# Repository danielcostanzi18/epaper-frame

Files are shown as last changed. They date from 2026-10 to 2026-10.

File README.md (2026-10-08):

# E-paper frame

3D-printed enclosure for a Waveshare 7.5" e-paper panel (800x480) driven by the Waveshare
e-Paper ESP32 Driver Board. It hangs on a wall (keyholes) or stands on a desk (removable
wedge feet), and has a Gateron low-profile key switch on the back.

- `docs/REQUIREMENTS.md` – hardware specs and design decisions
- `docs/ASSEMBLY.md` – print settings and assembly steps
- `docs/BOM.md` / `docs/bom.csv` – bill of materials
- `cad/epaper_frame.py` – parametric FreeCAD model (all parts); STL/STEP files and the coloured
  assembly are in `cad/out/`, earlier iterations in `cad/archive/`

Rebuild (FreeCAD 0.19):

```
cd cad
freecadcmd epaper_frame.py
QT_QPA_PLATFORM=offscreen freecad colour_assembly.py
```

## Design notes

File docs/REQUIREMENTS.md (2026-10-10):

# E-Paper Photo Frame — Requirements

3D-printed enclosure for a 7.5" e-paper panel driven by an ESP32. It can hang
on a wall or stand on a desk using removable feet.

## Hardware

| Item | Size (mm) | Notes |
|---|---|---|
| Waveshare 7.5" e-Paper raw panel V2 (800x480) | 170.2 x 111.2 x 1.18 | Active area 163.2 x 97.92. Borders: 3.5 on the sides and top, 9.78 on the FPC edge (the driver chip sits there) |
| Panel FPC tail | ~22 wide, 24 long | On a long edge, centred ~78 mm from one short end |
| FPC adapter board | 31.75 x 17.50 | Plugs onto the panel's FPC tail; FFC extension cable goes to the ESP32 |
| Waveshare e-Paper ESP32 Driver Board | 29.46 x 48.25 | **No mounting holes.** USB on a short edge, ESP32 module at the other end, FPC connector on a long side |
| Gateron KS-33 Low Profile 2.0 key switch (no keycap) | 15 x 15 top housing, 14 x 14 plate cutout, 12.2 total height, 3.0 travel | Clips into a 1.2 mm plate; 2 pins at (-4.4, 4.7) and (2.6, 5.75) from centre. Height split above/below the plate is assumed (6.0 / 6.2 incl. pins) |

Source: Waveshare panel spec PDF (7.5inch_e-Paper_V2_Specification.pdf, p.5) and the
ESP32 driver board manual. Board sizes were measured or confirmed by the user.

## Functional requirements
1. The panel is held in a rabbet (incastro). The bezel overlaps only the inactive border.
2. The panel must be removable without tools other than a screwdriver, and nothing may be glued to it.
3. The ESP32 sits behind the panel. It must not touch the panel or be stuck to it.
4. The ESP32 is held without mounting holes (clamped, not screwed).
5. USB power must be reachable from outside.
6. Wall mounting: keyhole slots.
7. Desk use: removable wedge feet screwed to the back, with nothing sticking out in front of the frame.

## Manufacturing constraints
- FDM, PLA, 220 x 220 mm bed. Every part prints flat without supports.
- Panel pocket (iteration 5): 1.5 mm bigger than the panel + clearance on every side, so the
  panel's sharp corners and edges touch nothing (a printer always rounds inside corners a little).
  The panel is located by 8 teeth, two per side at 1/4 and 3/4 of each edge, 8 mm wide, with
  0.45 mm clearance to the panel (0.3 mm printed too tight) and a 0.6 mm lead-in chamfer at the back.
- Fasteners: M3 button-head screws driven straight into the plastic, into Ø2.7 mm pilot holes
  (the first tightening cuts the thread). Every screw gets at least 4 mm of thread in plastic.
  Each hole has a 0.5 mm 45° chamfer at its mouth (Ø3.7 at the surface) to guide the screw in.

## Design decisions (implemented in cad/epaper_frame.py)
- Orientation: landscape, with the FPC edge at the bottom (the wide 9.78 mm border hides there).
- Bezel window: active area + 0.5 mm per side, offset to match the asymmetric border.
  The visible bezel is 17.4 mm on the sides and top and 23.7 mm at the bottom: wider at the bottom
  because the pixels sit off-centre on the glass (kept on purpose).
- The panel is pressed from behind by two vertical **panel straps** (14 x 132 x 4 mm, iteration 5),
  with 0.5 mm foam tape between straps and panel. Each strap is screwed to the bezel at both ends
  (4x M3 in total). They replace the full backer plate of iteration 4, which used ~5x more plastic.
- The bezel's back face has a 0.5 mm relief over the driver-chip strip, so nothing presses on the chip.
- A 50 mm wide relief at the bottom edge leaves room for the FPC tail to fold behind the panel.
- The adapter board lies on the back of the panel between the two straps, held by its two cables.
  There is 6 mm of free space either side of it, because the tail position depends on which end
  the 78 mm is measured from.
- The ESP32 sits on the back cover on 4 support pads. Corner locators hold it in place sideways,
  and a screwed strap with a foam pad presses on the module can.
- The ESP32 lies with its long edge horizontal and its USB end against the right-hand short wall
  (seen from the back). A 14 x 9 mm slot in that wall, centred on the board, lets the plug go in from outside.
- 2 keyholes, 100 mm apart, on the back cover (screw head up to 8 mm, shank up to 4 mm).
- 2 removable wedge feet (20 x 34 x 45 mm), each held by 2 screws straight into the back cover.
  The frame stands on its rear bottom edge plus the wedges, leaning back 20°. With no front
  support, 15° would leave the centre of mass only ~5 mm behind the tipping edge; 20° gives
  ~12 mm. The script checks this margin on every build.
- Overall size: 199.1 x 140.1 x 23.5 mm.
- Softened edges (iteration 3): the four vertical corners are rounded R4 on both the frame and
  the cover, so the side profile runs continuously across the joint. Edges that print on the bed
  get 45° chamfers: bezel front 1.5 mm, a 1 mm bevel round the viewing window, back cover 1 mm.
  The joint between frame and cover is left sharp so the two parts meet flush.
- Key switch (iteration 4): on the back cover, top centre, in line with the keyholes. It clips from
  outside into a 14 x 14 cutout in a 1.2 mm floor at the bottom of an 18 x 18 mm well, 6.5 mm deep,
  with a 1 mm chamfer round the rim. The bare stem stays 0.5 mm below the back surface, so the
  frame still sits flat on a wall. The cup sits 0.8 mm clear of the panel-strap level, allowing for the pins
  and soldered wires.
- Previous iterations are kept untouched in cad/archive/: iteration2/ (sharp edges), iteration3/
  (softened edges, no key switch), iteration4_heatset/ (heat-set inserts) and iteration4/ (full
  backer plate with adapter recess).

## Open items to verify on the real parts
1. The FPC tail is on the long edge with the wider (9.78 mm) border. If the window ends up
   off-centre, swap `AA_BORDER_TOP` and `AA_BORDER_FPC` in the script.
2. The ESP32 USB connector is assumed to be centred on its short edge, about 1.6 mm above the PCB.
3. The module can is assumed to be centred 15.5 mm from the board end opposite the USB.
   The strap must land on the metal can, not on the antenna.
4. Pilot hole size (`PILOT_D` = 2.7 mm): print a test piece. Go 2.5 if the screws feel loose,
   2.8 if the plastic cracks. Holes in the feet wear fastest, since they are removed most.
5. Key switch heights: measure the height above the plate (housing top to stem tip) and below it
   (to the pin tips); `KS_ABOVE` and `KS_BELOW` in the script assume 6.0 and 6.2 mm.

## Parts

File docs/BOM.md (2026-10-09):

# Bill of Materials — e-paper frame (iteration 4)

Same data as a spreadsheet: `bom.csv`. Part sizes and filament come from `cad/out/` (iteration 4).

## 1. Electronics

| # | Item | Spec | Qty | Used for | Notes |
|---|---|---|---|---|---|
| E1 | Waveshare 7.5" e-Paper raw panel V2 | 800x480, black/white, 170.2 x 111.2 x 1.18 mm | 1 | Display | |
| E2 | Waveshare e-Paper ESP32 Driver Board | 29.46 x 48.25 mm, USB-C | 1 | Controller | Ships with E3 and E4 |
| E3 | e-Paper FPC adapter board | 31.75 x 17.50 mm | 1 | Panel FPC → FFC | Included with E2 |
| E4 | FFC extension cable | 24-pin, 0.5 mm pitch | 1 | Adapter → ESP32 | Included with E2 |
| E5 | Gateron KS-33 Low Profile 2.0 switch | 3-pin, plate-mount for a 1.2 mm plate, any colour | 1 | Button on the back | Used without a keycap |
| E6 | Hook-up wire | AWG 26–28, ~2 x 25 cm | 1 set | Switch → ESP32 GPIO + GND | Solder to the switch pins |
| E7 | USB-C cable + 5 V supply | ≥ 0.5 A | 1 | Power | The plug body must pass a 14 x 9 mm slot |

## 2. Printed parts (PLA, no supports)

| # | Part | File | Qty | Size (mm) | Filament (est.) | Print orientation |
|---|---|---|---|---|---|---|
| P1 | Frame (bezel + walls) | frame.stl | 1 | 199.1 x 140.1 x 20.5 | ~80 g | Front face down |
| P2 | Backer | backer.stl | 1 | 170.7 x 132.1 x 4.0 | ~70 g | Flat back face down |
| P3 | Back cover | back_cover.stl | 1 | 199.1 x 140.1 x 9.7 | ~95 g | Outer face down |
| P4 | ESP32 strap | esp32_strap.stl | 1 | 10.0 x 47.5 x 2.5 | ~1.5 g | Flat |
| P5 | Desk wedge foot | foot.stl | 2 | 20.0 x 34.0 x 45.0 | ~10 g each | Screw face down |
| | **Total** | | | | **~265 g** | Solid parts would be ~335 g |

Filament estimates assume 3 walls, 4 top/bottom layers and 20 % infill. Every part fits a 220 x 220 mm bed.

## 3. Fasteners

| # | Item | Spec | Qty | Used for |
|---|---|---|---|---|
| F1 | Button-head screw | M3 x 10 | 8 | 4 back cover → frame corners, 4 feet (2 per foot) |
| F2 | Button-head screw | M3 x 6 | 4 | Backer → frame |
| F3 | Button-head screw | M3 x 8 | 2 | ESP32 strap → back cover |
| F4 | Wall screw + plug | Head Ø ≤ 8 mm, shank Ø ≤ 4 mm | 2 | Wall mounting, 100 mm apart. Optional, wall use only |

All screws thread straight into Ø2.7 mm pilot holes in the plastic; the first tightening cuts the
thread. Plain M3 machine screws work. Don't overtighten, and buy a couple of spares.

## 4. Consumables

| # | Item | Spec | Qty | Used for |
|---|---|---|---|---|
| C1 | Foam tape | 0.5 mm thick, ~5 mm wide, ~60 cm | 1 | Between backer and panel, round the edge |
| C2 | Foam pad | 1 mm thick, ~10 x 15 mm | 1 | Between strap and ESP32 module can |
| C3 | Thin double-sided or Kapton tape | small piece | 1 | Optional: holds the adapter board in its recess (never on the panel) |

## 5. Tools
Soldering iron (switch wires), M3 hex/screwdriver, flush cutters.

## Not included / open
- No battery: the ESP32 board has a LiPo connector, but the enclosure has no battery bay yet.
- The key switch heights are assumed (6.0 mm above / 6.2 mm below the plate). Check them on the
  real switch before printing P3.

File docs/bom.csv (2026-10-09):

ID | Category | Item | Spec | Qty | Unit | Used for | Notes
E1 | Electronics | Waveshare 7.5in e-Paper raw panel V2 | 800x480 B/W, 170.2 x 111.2 x 1.18 mm | 1 | pcs | Display
E2 | Electronics | Waveshare e-Paper ESP32 Driver Board | 29.46 x 48.25 mm, USB-C | 1 | pcs | Controller | Ships with E3 and E4
E3 | Electronics | e-Paper FPC adapter board | 31.75 x 17.50 mm | 1 | pcs | Panel FPC to FFC | Included with E2
E4 | Electronics | FFC extension cable | 24-pin, 0.5 mm pitch | 1 | pcs | Adapter to ESP32 | Included with E2
E5 | Electronics | Gateron KS-33 Low Profile 2.0 switch | 3-pin, plate mount, 1.2 mm plate | 1 | pcs | Button on the back | No keycap
E6 | Electronics | Hook-up wire | AWG 26-28, 2 x 25 cm | 1 | set | Switch to ESP32 GPIO + GND
E7 | Electronics | USB-C cable + 5 V supply | >= 0.5 A | 1 | pcs | Power | Plug body must pass a 14 x 9 mm slot
P1 | Printed | Frame | frame.stl 199.1 x 140.1 x 20.5 mm | 1 | pcs | Bezel + walls | PLA ~80 g, front face down
P2 | Printed | Backer | backer.stl 170.7 x 132.1 x 4.0 mm | 1 | pcs | Presses panel into bezel | PLA ~70 g, flat back face down
P3 | Printed | Back cover | back_cover.stl 199.1 x 140.1 x 9.7 mm | 1 | pcs | Closes the enclosure | PLA ~95 g, outer face down
P4 | Printed | ESP32 strap | esp32_strap.stl 10.0 x 47.5 x 2.5 mm | 1 | pcs | Clamps ESP32 | PLA ~1.5 g, flat
P5 | Printed | Desk wedge foot | foot.stl 20.0 x 34.0 x 45.0 mm | 2 | pcs | Desk stand (20 deg) | PLA ~10 g each, screw face down
F1 | Fastener | Button-head screw | M3 x 10 | 8 | pcs | 4 cover to frame corners, 4 feet | Into 2.7 mm pilot holes in plastic
F2 | Fastener | Button-head screw | M3 x 6 | 4 | pcs | Backer to frame | Into 2.7 mm pilot holes in plastic
F3 | Fastener | Button-head screw | M3 x 8 | 2 | pcs | ESP32 strap to cover | Into 2.7 mm pilot holes in plastic
F4 | Fastener | Wall screw + plug | head <= 8 mm, shank <= 4 mm | 2 | pcs | Wall mounting (optional) | 100 mm apart
C1 | Consumable | Foam tape | 0.5 mm thick, 5 mm wide | 60 | cm | Backer to panel edge
C2 | Consumable | Foam pad | 1 mm thick, 10 x 15 mm | 1 | pcs | Strap to ESP32 module can
C3 | Consumable | Double-sided or Kapton tape | small piece | 1 | pcs | Adapter board in its recess (optional) | Never on the panel

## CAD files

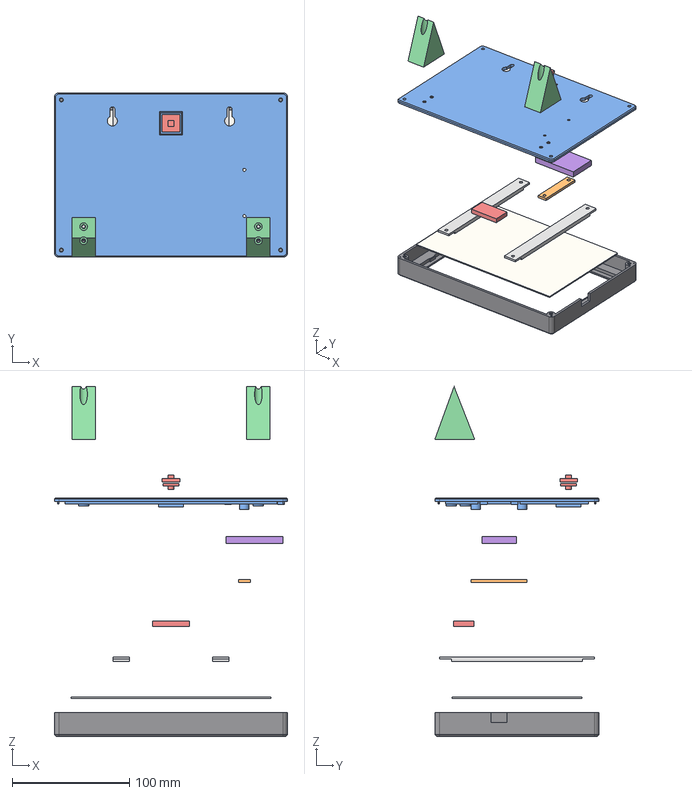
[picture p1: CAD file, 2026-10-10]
cad/out/assembly_exploded.FCStd
199.1 x 140.1 x 298.5 mm
frame
ref_panel
panel_strap_1
panel_strap_2
ref_adapter
esp32_strap
ref_esp32
ref_key_switch
back_cover
foot_1
foot_2

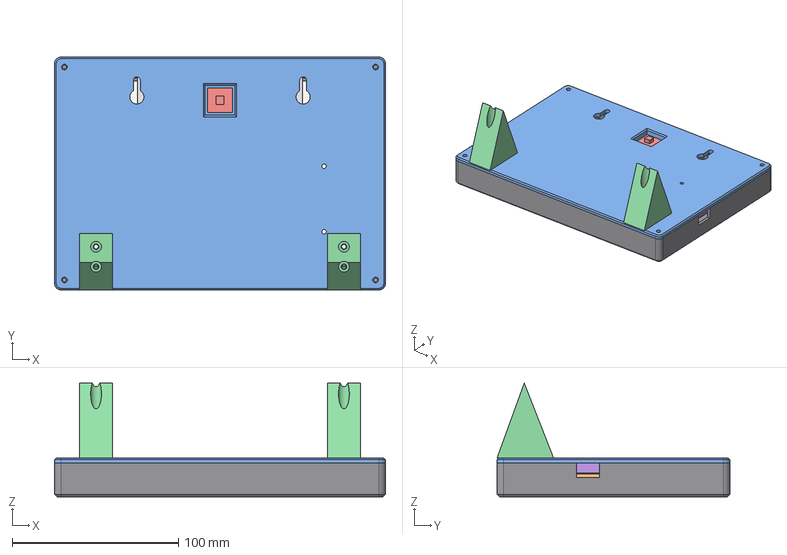
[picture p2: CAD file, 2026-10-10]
cad/out/assembly.FCStd
199.1 x 140.1 x 68.5 mm
frame
ref_panel
panel_strap_1
panel_strap_2
ref_adapter
esp32_strap
ref_esp32
ref_key_switch
back_cover
foot_1
foot_2

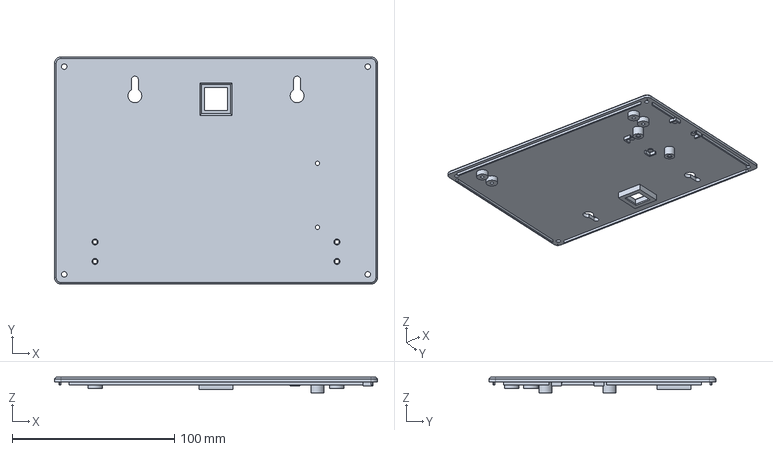
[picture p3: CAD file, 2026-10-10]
cad/out/back_cover.step
199.1 x 140.1 x 9.70 mm

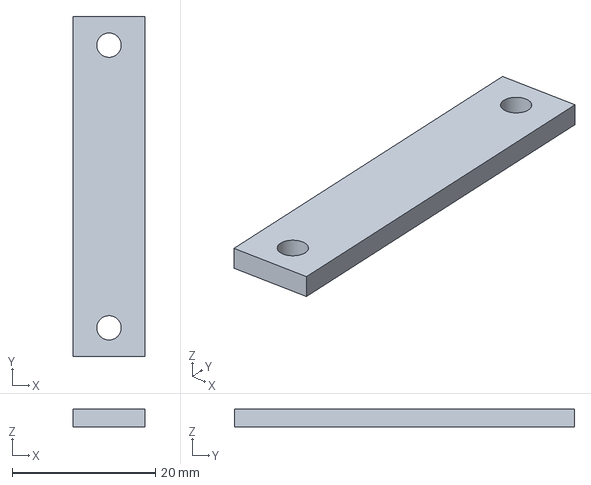
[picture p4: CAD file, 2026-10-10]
cad/out/esp32_strap.step
10.0 x 47.5 x 2.50 mm

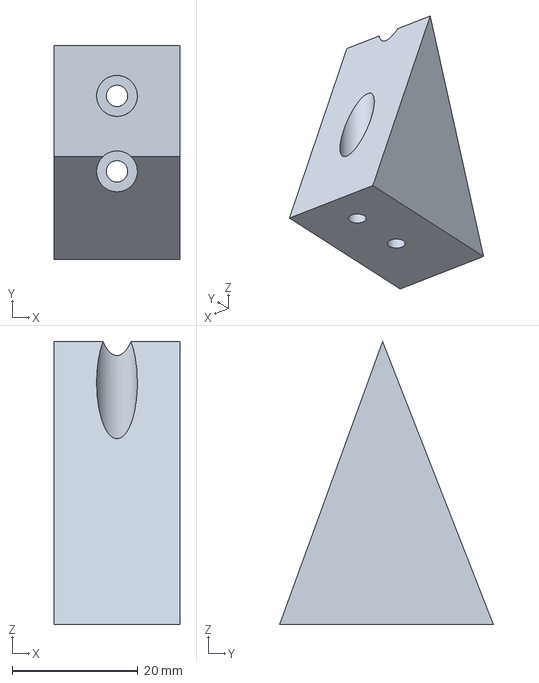
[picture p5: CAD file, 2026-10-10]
cad/out/foot.step
20.0 x 34.0 x 45.0 mm

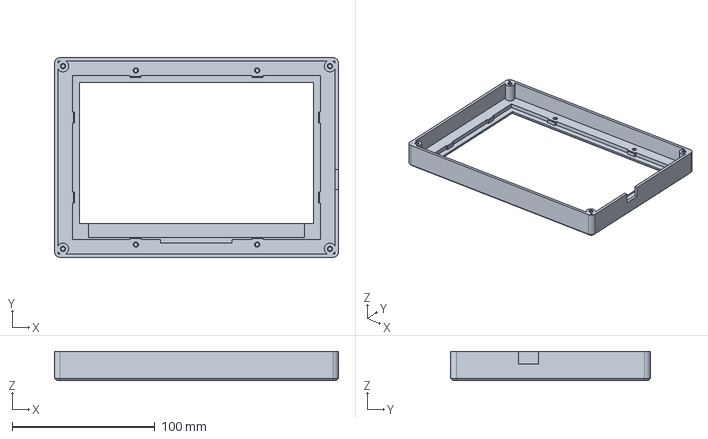
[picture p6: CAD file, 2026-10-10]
cad/out/frame.step
199.1 x 140.1 x 20.5 mm

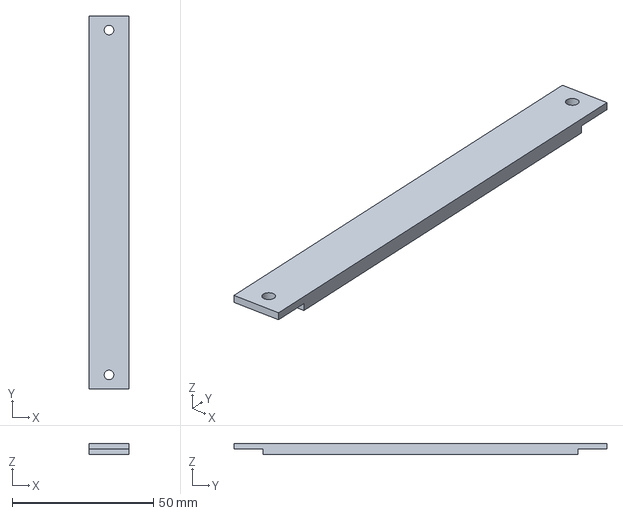
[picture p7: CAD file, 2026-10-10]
cad/out/panel_strap.step
14.0 x 132.1 x 4.00 mm

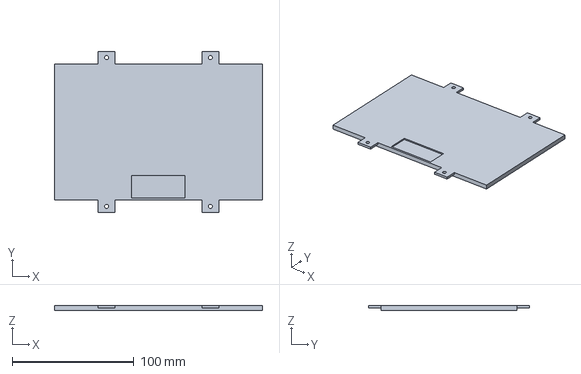
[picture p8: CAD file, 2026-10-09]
cad/out/backer.step
170.7 x 132.1 x 4.00 mm

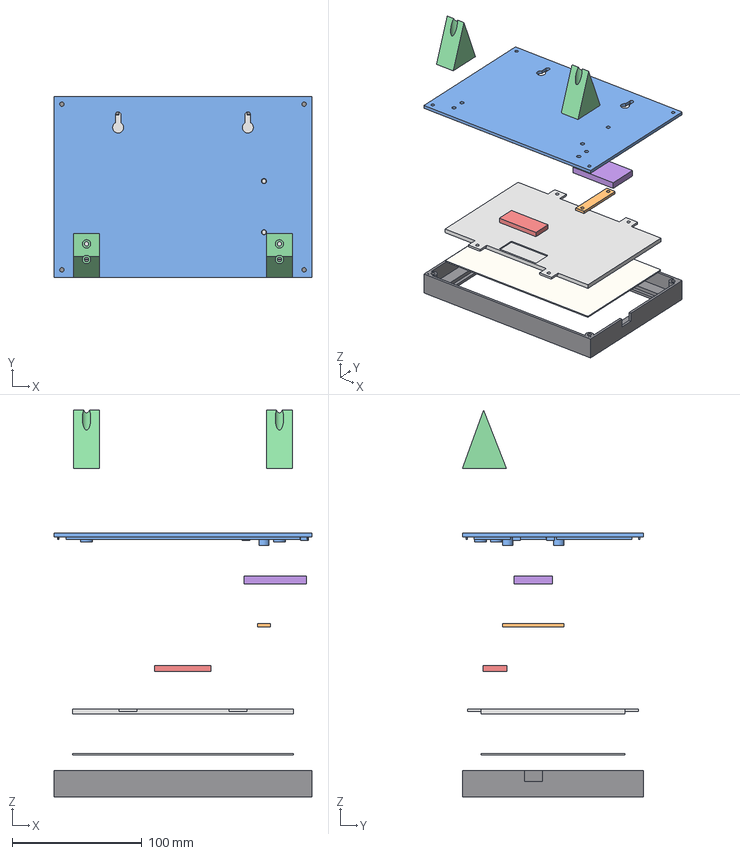
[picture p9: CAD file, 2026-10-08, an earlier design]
cad/archive/iteration2/assembly_exploded.FCStd
198.8 x 139.8 x 298.5 mm
frame
ref_panel
backer
ref_adapter
esp32_strap
ref_esp32
back_cover
foot_1
foot_2

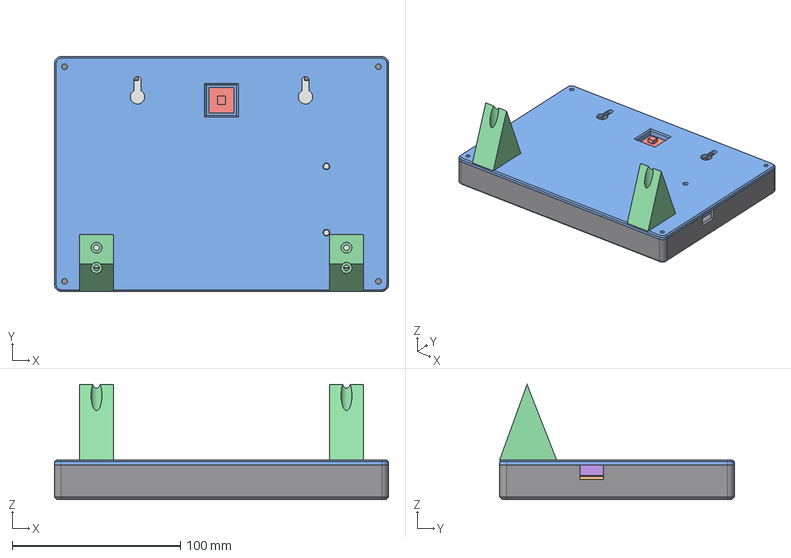
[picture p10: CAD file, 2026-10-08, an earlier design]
cad/archive/iteration4_heatset/assembly.FCStd
198.8 x 139.8 x 68.5 mm
frame
ref_panel
backer
ref_adapter
esp32_strap
ref_esp32
ref_key_switch
back_cover
foot_1
foot_2

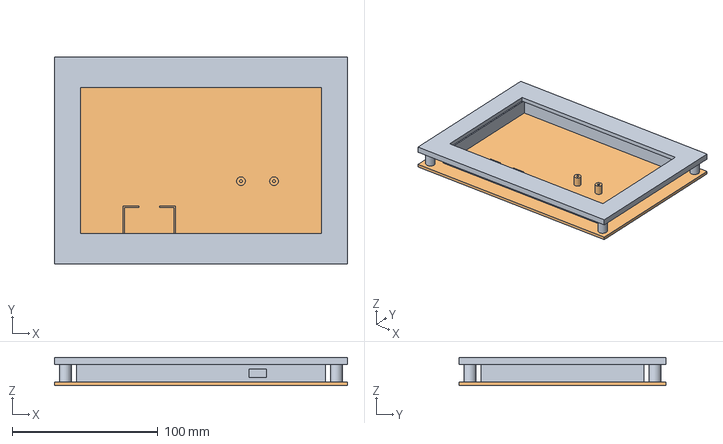
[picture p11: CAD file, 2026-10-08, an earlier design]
cad/archive/iteration2_assembly.FCStd
200.8 x 141.8 x 19.5 mm
Frame
BackCover

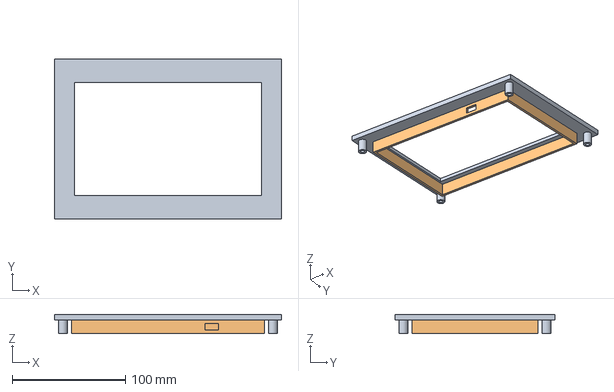
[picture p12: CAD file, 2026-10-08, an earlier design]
cad/archive/iteration2_frame.step
200.8 x 141.8 x 17.0 mm

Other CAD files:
cad/archive/iteration3/assembly_exploded.FCStd
cad/archive/iteration4/assembly.FCStd
cad/archive/iteration3/assembly.FCStd
cad/archive/iteration4/assembly_exploded.FCStd
cad/archive/iteration4_heatset/assembly_exploded.FCStd
cad/archive/iteration2/assembly.FCStd
cad/archive/iteration1_frame.FCStd
cad/archive/iteration1_frame.step
cad/archive/iteration1_frame.stl
cad/archive/iteration2/assembly.obj
cad/archive/iteration2/assembly_exploded.obj
cad/archive/iteration2/back_cover.step
cad/archive/iteration2/back_cover.stl
cad/archive/iteration2/backer.step
cad/archive/iteration2/backer.stl
cad/archive/iteration2/esp32_strap.step
cad/archive/iteration2/esp32_strap.stl
cad/archive/iteration2/foot.step
cad/archive/iteration2/frame.step
cad/archive/iteration2/frame.stl
cad/archive/iteration2_back_cover.FCStd
cad/archive/iteration2_back_cover.step
cad/archive/iteration2_back_cover.stl
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

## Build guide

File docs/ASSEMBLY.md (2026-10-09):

# Assembly

## Look at it first
- `cad/out/assembly.FCStd` (assembled) and `cad/out/assembly_exploded.FCStd` open in FreeCAD with
  one colour per part. `assembly*.obj` are the same models for any other 3D viewer.
- Colours: frame dark grey, panel off-white, backer light grey, adapter board red, strap orange,
  ESP32 purple, back cover blue, feet green. The panel and the two boards are stand-in blocks.
- To regenerate everything: `freecadcmd epaper_frame.py`, then
  `QT_QPA_PLATFORM=offscreen freecad colour_assembly.py`.

## Print (PLA, no supports)
| Part | Qty | Orientation |
|---|---|---|
| frame.stl | 1 | front face down |
| backer.stl | 1 | flat back face down (adapter recess on the bed) |
| back_cover.stl | 1 | outer face down (the key switch floor is a 2 mm overhang round the cutout: no supports needed) |
| esp32_strap.stl | 1 | flat |
| foot.stl | 2 | flat face (the one that screws to the cover) down |

## Hardware
- M3 button-head screws, driven straight into Ø2.7 mm pilot holes in the plastic (each with a small chamfer at the mouth):
  8x M3x10 (4 cover corners, 4 feet), 4x M3x6 (backer), 2x M3x8 (strap).
  The first tightening cuts the thread: go in slowly and stop as soon as the head seats.
- 1x Gateron KS-33 Low Profile 2.0 switch
- 0.5 mm foam tape (backer → panel), a 1 mm foam pad (strap → ESP32 module)

## Steps (looking at the back)
1. Lay the frame face down. Drop the panel into the pocket with the FPC tail at the **bottom** edge.
2. Stick strips of 0.5 mm foam tape around the edge of the backer's flat side.
   Lay the backer on the panel and fix it with 4x M3x6.
3. Fold the FPC tail gently (don't crease it) round the backer's bottom edge, through the gap
   at the bottom of the pocket. Plug it into the adapter board, then seat the adapter in the
   backer's recess. Slide it sideways until the tail lies flat. A small piece of tape onto the
   backer is fine; never tape anything to the panel.
4. Connect the FFC extension cable to the adapter board.
5. Place the ESP32 on the back cover's 4 pads inside the corner locators, USB end towards the
   right-hand short side (seen from the back). Put the 1 mm foam pad on the module can and
   screw the strap down (2x M3x8).
6. Plug the FFC cable into the ESP32 and tuck the spare length away from the strap.
7. Key switch: push it into the well on the outside of the back cover until its clips snap under
   the 1.2 mm floor. Solder two wires to its pins and connect them to a free ESP32 GPIO and GND
   (enable the internal pull-up). Keep the wires flat against the cover.
8. Close the back cover. Its lip goes inside the walls. Fix it with 4x M3x10.
9. Plug USB-C in through the slot in the short side wall.

## Wall or desk
- **Wall:** two screws in the wall, 100 mm apart and level, sticking out about 5 mm (head up to 8 mm,
  shank up to 4 mm). Push the heads through the round holes of the keyholes, then let the frame
  drop so the shanks slide into the slots. The heads catch on the inside of the cover.
- **Desk:** screw the two wedges onto the back cover, thin end up (2x M3x10 each, through the
  counterbores). The frame stands on its bottom back edge and the wedges, leaning back 20°.

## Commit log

2026-10-08 Add parametric FreeCAD model of the e-paper photo frame
    3D-printed enclosure for the Waveshare 7.5" e-paper panel and ESP32 driver
    board: bezel, panel backer, back cover with ESP32 cradle, keyholes, low-profile
    key switch and removable desk wedges. Includes STL/STEP outputs,
    earlier iterations, requirements, assembly notes and BOM.
    [assembly.FCStd, assembly.obj, assembly_exploded.FCStd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]
2026-10-09 Loosen the panel pocket and chamfer the screw holes
    The first print showed the panel too tight in its pocket, so the clearance
    goes from 0.3 to 0.45 mm per side (the frame, backer and cover grow by
    0.3 mm). Every pilot hole a screw threads into now has a 0.5 mm 45 deg
    lead-in chamfer. Parts, assemblies, BOM and requirements are regenerated
    to match.
    [assembly.FCStd, assembly.obj, assembly_exploded.FCStd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]
2026-10-10 Replace the backer plate with two panel straps
    The full backer plate used a lot of plastic and its adapter-board recess
    made it hard to print, while all it needs to do is press the panel into
    the bezel. Two identical vertical straps do that, screwed into the same
    four holes; the adapter board now hangs on its cables between them.
    Iteration 4 is archived in cad/archive/iteration4/.
    [assembly.FCStd, assembly.obj, assembly_exploded.FCStd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]
2026-10-10 Locate the panel with eight teeth instead of full pocket walls
    The printed pocket's inside corners come out rounded while the panel's are
    sharp, so the panel bound in the corners. The pocket is now 1.5 mm larger
    on every side and the panel is located by two teeth per side (0.45 mm
    clearance, 0.6 mm lead-in chamfer), leaving its corners and edges free.
    [assembly.FCStd, assembly.obj, assembly_exploded.FCStd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]
